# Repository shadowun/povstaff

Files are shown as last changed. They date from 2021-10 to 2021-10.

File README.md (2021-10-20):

# POV staff
This repository contains all files related to Persistence of Vision (POV) staff
project. A detailed write-up of this project is available on  Instructables at
[https://www.instructables.com/Persistence-of-Vision-LED-Staff/](https://www.instructables.com/Persistence-of-Vision-LED-Staff/);
you can also find there photos  of the staff in action.

A guide for using the assembled staff and uploading images to it is available
in directory `docs`; see file USER_GUIDE.md and USER_GUIDE.pdf for PDF version.

## Structure of this repository  
This repository is organized as follows:

* `binaries`: pre-complied binaries
* `docs`: documentation
* `hardware`:  design files for the custom PCBs used in
  the project, as well as STEP files for the 3d printed components.
* `images`: sample image(s) and  `imagelist.txt` file

## Authors and license
This project was created by Alexander Kirillov <shurik179@gmail.com>; it is
based on [earlier work](https://learn.adafruit.com/pov-dotstar-double-staff) of
Phillip Burgess and Erin St Blaine from Adafruit. The project is available under
MIT license; see LICENSE file for details.

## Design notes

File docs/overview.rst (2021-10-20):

*********************
Overview
*********************

It is well known that even after a light has been turned off, human eye keeps
"seeing" it for a fraction of second. This is known as Persistence of Vision, or
POV, and it allows one to "paint" pictures by quickly moving a strip of LEDs,
drawing one line of an image at a time in quick succession. If you search online
(e.g. on Etsy), you can find quite a few toys based on this idea: pois, staffs,
and more.

However, these are expensive: typical prices for a POV staff of decent
resolution start at $500, and they use proprietary software, so there is no easy
way to modify their behavior or add extra functionality. Thus, when looking for
a birthday gift for a friend who enjoys painting with light, I decided to create
my own open source version using readily available components.

My project builds upon the outstanding `work of Phillip Burgess and Erin St
Blaine <https://learn.adafruit.com/pov-dotstar-double-staff>`__ from Adafruit;
however, I made a few changes, upgrading the electronics.
Below are key features of this project:

* It is a two-sided staff, of total length 141 cm (55in); it is not collapsible.
  Each side of the staff has two 50cm/72 pixels LED strips, for the total of 288
  LEDs. Thus, you can use it to show images with 72-px resolution.

* Staff is powered by two 18650 Li-Ion batteries, which should be enough for at
  least 1 hr show, possibly as much as 2 hours, depending on intensity of your
  images. The batteries can be recharged via micro-USB connector; full charge
  time is about 5 hrs.

* Images (in bitmap format) can be easily uploaded to the
  staff by connecting the staff to a computer, where it appears as a USB
  storage device. It has enough memory for about 50 images. The order in which
  images are shown is described in a separate plain text file, where you can
  put a list of images and durations. An image can be listed there several
  times, or none at all.

* The staff contains an Inertial Motion Unit (IMU) which can be used to
  detect when the staff is in motion. The software uses it to adjust update
  frequency for images, so the images will not appear stretched or compressed
  regardless of how fast you are rotating it. You can also use it for
  controlling your show: e.g. stopping the staff horizontally is used as a
  signal to move to the next image in the slideshow. The software is based on
  Arduino IDE. It is available under an open source license and is easy to
  modify to suit your needs.

This project is open source; all code and schematics are available in my github
repository under MIT license.

For those who want to create your own staff, you can buy a kit of parts, which
includes most of the parts needed (except for LED strips and tube), from my
`Tindie store <https://www.tindie.com/stores/irobotics/>`__. Of course, you
can also build your own by sourcing all components independently -- see
building instructions for details.

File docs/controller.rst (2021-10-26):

=====================
Soldering
=======================
Solder the male headers to the ItsyBitsy; for ItsyBitsy M4, only solder the
headers along the two long sides of the board. Now solder the POV shield board
to these headers underneath the Itsy Bitsy, forming a "sandwich" of two boards
as shown in the photos above. Note: all components of the POV shield should be
on the outside, not inside the sandwich!

After you are done soldering, use diagonal cutters to trim the long pins of the
headers so they are not in the way.

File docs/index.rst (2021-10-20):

===========================
Persistence of Vision Staff
===========================
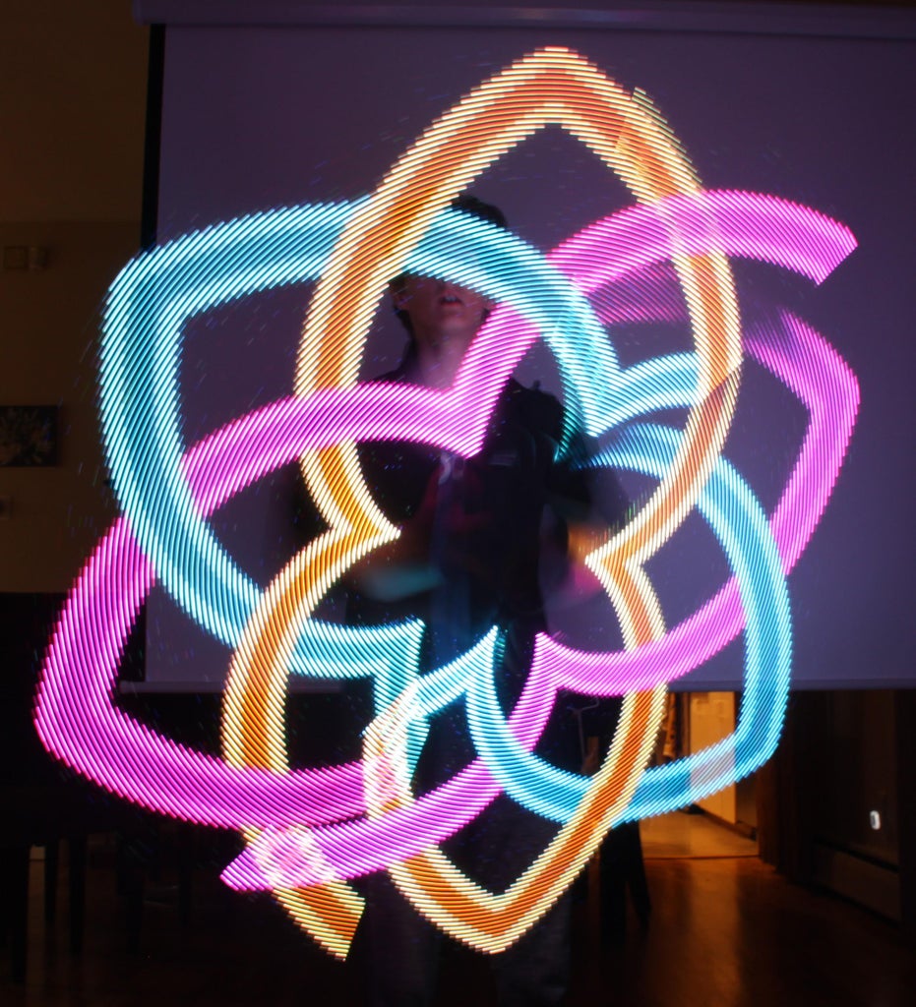
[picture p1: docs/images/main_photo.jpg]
Staff in action


This is documentation for Persistence of Vision (POV) staff, created  by Alexander
Kirillov (based on earlier work of ). An earlier version of this project has
been published on `Instructables <https://www.instructables.com/Persistence-of-Vision-LED-Staff/>`__.
This document describes a new and improved Version 2, created in 2021.

All design files and code are opne source.

.. toctree::
    :caption: Table of Contents
    :maxdepth: 2

    overview
    build
    usage

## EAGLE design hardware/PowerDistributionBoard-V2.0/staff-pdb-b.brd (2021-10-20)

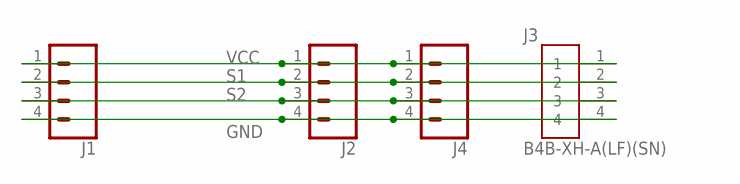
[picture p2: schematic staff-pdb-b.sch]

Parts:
J1, J2, J4: CONN_04; 1X04
J3: B4B-XH-A(LF)(SN); JST_B4B-XH-A(LF)(SN)

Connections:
GND: J1.4, J2.4, J3.4, J4.4
S1: J1.2, J2.2, J3.2, J4.2
S2: J1.3, J2.3, J3.3, J4.3
VCC: J1.1, J2.1, J3.1, J4.1

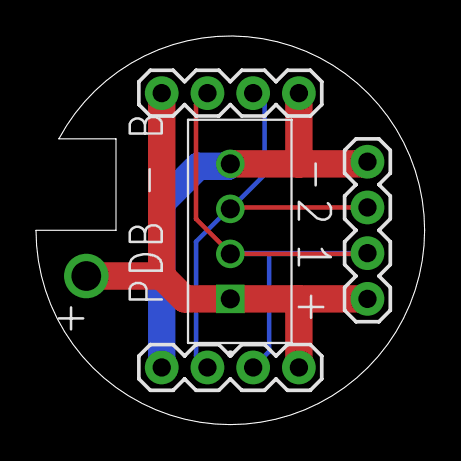
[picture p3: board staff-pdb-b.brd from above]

Board: 2 copper layers, 21.6 x 21.6 mm, 4 parts (0 on the bottom side), 4 nets.

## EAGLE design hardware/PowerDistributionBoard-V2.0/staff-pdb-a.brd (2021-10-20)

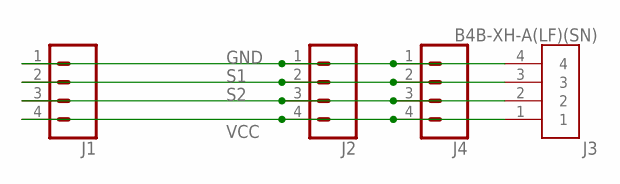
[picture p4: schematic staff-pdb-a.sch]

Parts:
J1, J2, J4: CONN_04; 1X04
J3: B4B-XH-A(LF)(SN); JST_B4B-XH-A(LF)(SN)

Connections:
GND: J1.1, J2.1, J3.4, J4.1
S1: J1.2, J2.2, J3.3, J4.2
S2: J1.3, J2.3, J3.2, J4.3
VCC: J1.4, J2.4, J3.1, J4.4

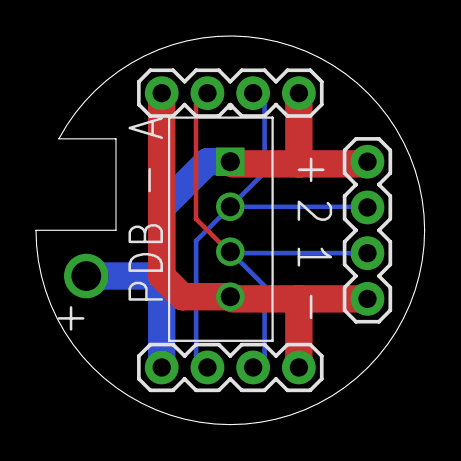
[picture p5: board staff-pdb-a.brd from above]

Board: 2 copper layers, 21.6 x 21.6 mm, 4 parts (0 on the bottom side), 4 nets.

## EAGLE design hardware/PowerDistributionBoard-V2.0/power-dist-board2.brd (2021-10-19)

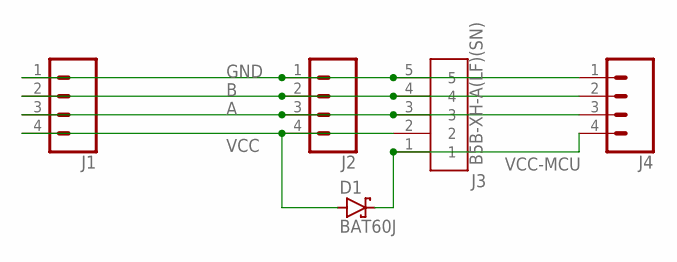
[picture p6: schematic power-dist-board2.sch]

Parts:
D1: BAT60J; SOD323_ST
J1, J2, J4: CONN_04; 1X04
J3: B5B-XH-A(LF)(SN); JST_B5B-XH-A(LF)(SN)

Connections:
A: J1.3, J2.3, J3.3, J4.3
B: J1.2, J2.2, J3.4, J4.2
GND: J1.1, J2.1, J3.5, J4.1
VCC: D1.A, J1.4, J2.4, J3.2
VCC-MCU: D1.C, J3.1, J4.4

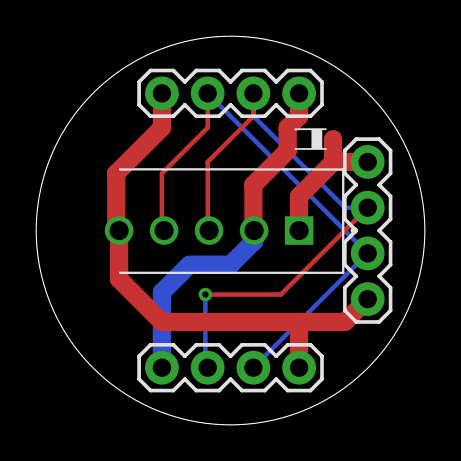
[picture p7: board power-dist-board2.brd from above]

Board: 2 copper layers, 21.6 x 21.6 mm, 5 parts (0 on the bottom side), 5 nets.

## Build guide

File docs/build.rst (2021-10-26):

*********************
Building instructions
*********************
Below you can find the instructions for building your own POV staff. These
instructions assume that you are using a kit of parts bought from my
`Tindie store <https://www.tindie.com/stores/irobotics/>`__. Some information
on modifying these instructions if you want to source your components independently
is given in section FIXME.

You will need the following materials:

* Kit of parts from https://www.tindie.com/stores/irobotics/

* APA102 (DotStar) LED strip, 144 LED/meter, black PCB. They are  found from
  many vendors, including  `Adafruit <https://www.adafruit.com/product/2241>`__
  and a number of vendors on Amazon and Aliexpress, such as `<https://www.aliexpress.com/item/32322326979.html>`__.
  You need 4 strips of 50cm (72 LEDs) each; you can also buy longer strips
  and cut them into 50cm pieces. The strips should **not** be waterproofed
  (sometimes this is listed as IP30). Adafruit strips come with waterproof
  silicone sheathing which you can just remove and discard.

* Two 18650 Li-Ion batteries. Look for high-capacity (at least 3000mAh),
  **protected batteries** from a reputable manufacturer such as Panasonic, Samsung,
  or Sanyo; I recommend `these batteries
  <https://www.18650batterystore.com/collections/button-top-18650-batteries/products/panasonic-18650-protected>`__
  by Panasonic. Do not try to  save money by buying a no-name battery on eBay or Amazon.

* Polycarbonate tube, `11F(55in/141cm) <https://flowtoys.com/long-tubes-5f-to-13f>`__,
  1 inch outer diameter, from flowtoys.com

* 1/2 inch square wood dowel, from HomeDepot or any other hardware store.
  You need 4 ft (or two 2ft pieces)

In addition, you will need some spray black paint, a soldering iron, and some
common tools: sharp knife, saw (for cutting wood dowel), diagonal cutters for
trimming header pins, scissors. Needless to say, you will also need a computer
to program the microcontroller and a USB charger to charge the batteries.

.. toctree::
    :caption: Steps
    :maxdepth: 2

    build_overview
    led_assemblies
    controller

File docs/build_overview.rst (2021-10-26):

========================
Overview of build steps
========================

The assembled staff will consist of the following subassemblies:

* Two 18650 batteries and wiring in the middle of the staff. The batteries are
  separated from each other and from LED assemblies by 3d printed spacers; total
  length of the batteries+spacers is about 25 cm.

* Two LED assemblies, one on each side of the staff. Each assembly consists of
  two 50 cm LED strips attached to a wood dowel. The LED strips will be soldered
  to a round power distribution board at the interior end of the dowel. The LED
  assembly are connected to each other and battery by JST XH connectors,
  plugging into the headers on power distribution boards.

* At one end of the staff, there is a switch, with two wires leading from it to
  the batteries in the middle and protected by a PVC endcap with an opening for the
  switch

* At the opposite end of the staff, the controller, consisting of the ItsyBitsy
  microcontroller attached to the custom POV shield board, protected by PVC endcap.
  A 4-wire cable is plugged into the JST XH header on the POV shield; the wires
  run the length of LED assembly to the center

* Tennis racket grip tape covering the battery assembly in the middle of the
  staff, for better grip.

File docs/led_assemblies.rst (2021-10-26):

============================
Making the LED assemblies
============================

1. Take the 1/2 inch wood dowels and cut them using hacksaw to produce two
   pieces of 52cm each. Try to keep your cuts square.

2. Spray-paint the pieces black and leave to dry. This will give the staff a
   much more polished look (while it is off; once it is on, no one will notice
   what color the dowels are).

3. Get the LED strip(s). If they are inside waterproof sheaving, remove and
   discard the sheaving. If they have any wires soldered, de-solder them;
   remove excess solder using a braid wick. If you ordered 1m or 2m strips, cut
   them into 50 cm pieces, making sure to leave as large as possible soldering
   pads in the beginning of each strip (this should be easy, as usually longer
   strips are created by soldering together 50cm ones, so you will be just
   undoing someone else's work).

4. Using your soldering iron, tin the pads in the beginning of each LED strip.
   Take the solid core wire included in the kit of parts; strip insulation from
   about 2cm  long piece but do not cut it. Using the insulated part to hold the
   wire, solder it to the top pad on the strip. You will be soldering very
   close to the first LED, so please watch your iron carefully - do not touch the LED!
   After soldering, cut the soldered piece and repeat the process with all
   other pads. The end result should look similar to the one shown below:

5. Now    
All APA102 strips have 4 signal lines: Ground (GND, commonly abbreviated G), Clock (CLK, or CI for Clock In), Data (DAT, or DI), and VCC, or 5V. However, the order of these signal lines on the strips is varies between manufacturers. Thus, now is a good time to write it down for future use. Put the strip on the desk with the beginning of the strip to the left, and write down the signals, going from top to bottom and labeling them A... D. For example, for the strip in the photos above you would get the following list:
A=GND
B=CLK
C=DAT
D=VCC
Keep this list readily available through the rest of assembly - you will refer to it more than once.

Remove the backing paper from the adhesive strip on the back of the LED and attach the strip to the wood dowel so that the plastic spacers on the soldered headers are flush with the end of the dowel. Attach the other strip to the opposite side of the dowel. Repeat with the other dowel.
Take the power distribution boards and solder them to the headers as shown in the photos. The boards should be flush with the end of the wood dowel. Use diagonal cutters to cut off extra length of header pins.
You should now have two completed LED assemblies.
Note: the adhesive on LED strips is not very strong, so your strips might start peeling off. It is OK; we will make a more permanent attachment later.

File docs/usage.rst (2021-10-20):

*********************
User guide
*********************


This document describes the use of the POV staff. It assumes you have already
fully assembled it and uploaded the software. For more information, please
check the description of the project on instructables.com:
https://www.instructables.com/Persistence-of-Vision-LED-Staff/

The latest version of this document can always be found on the project github page:
https://github.com/shurik179/povstaff

## Turning on/off
To turn the staff on and off, use the switch at one end of the staff. As soon
as you have turned it on, it will show the battery voltage, by lighting part
of the LED strips. The longer the strip, the higher the battery charge.

If you only see one or two LEDs light up, the battery charge is too low for
use. You need to recharge the batteries as described below.

After using the staff, **make sure to turn it off**! If left on, LEDs will
drain the battery rather fast - even if you are not using the staff. To remind
you to turn it off, the staff will be blinking  red LEDs once every 30 seconds
while it is on and not being used.

## Charging/recharging
To charge the staff, remove the endcap from the end opposite to the switch.
Inside you will see a microcontroller with a micro-USB connector. Plug in a
USB charger; for best results, use a charger that can provide at least 1A
charging current.

For charging, the switch must be in ON position. Once you completed charging,
remember to switch the staff off.

Full charge should take about 5 hrs.

## Uploading images and creating image list
To upload images, make sure the switch is OFF and connect the staff to a
computer. It should appear as an external USB drive - as if you had plugged
in a USB flash drive. Just drag the images to the staff to upload. All images
must be saved to the root directory of the staff drive - please do not create
subdirectories.

Technical requirements for images:

* Images must be in bitmap (BMP) format, with 24 bit color depth. Use any
  software you like to convert images in other formats to bmp - e.g. you can use
  Microsoft Paint 3D.

* Maximal image size is 72x288 pixels. It is recommended to use images with
  width of 72 pixels - to match the number of LEDs on the staff

* Image filenames must be at most 30 symbols long and can only contain letters,
  numbers, dashes and underscores. No spaces or special symbols!

You can create your own images or search for existing ones.  A good source for
POV image patterns is [Visual  POI Zone](https://visualpoi.zone/patterns/).
When downloading images from there, make sure to choose *Visual poi V4 mini (72px)*
option. You will also need to rotate images 90 degrees.

Please note that the same color (i.e. the same RGB values) can look quite
different on the screen of your computer and on LED strip. Experiment with
colors to get some feel for it.

Once you have uploaded the images, you need to create a list showing in which
order these images should be played during the show. Create the file
`imagelist.txt` in the root directory of the POV staff (or open the file if
it already exists) and put there the list of image files in the order you want
to use them in your show, one filename per line, including `.bmp` extension.
Optionally, you can also add how long the image should be shown, in seconds
(whole numbers only!), separated from  filename by one or more spaces
```
image1.bmp 20
image2.bmp 41
image5.bmp 10
image1.bmp
```
You can include some image file more than once, or not at all - it is your
choice. The name of your image list must be `imagelist.txt`, all lower case.

Once you have saved the image list,  eject the POV staff as you would normally
do a USB flash drive, and unplug the cable.

To help you figure out correct rotation and orientation of images, the pictures
below show the same image in BMP file and how it will look when using the POV staff.

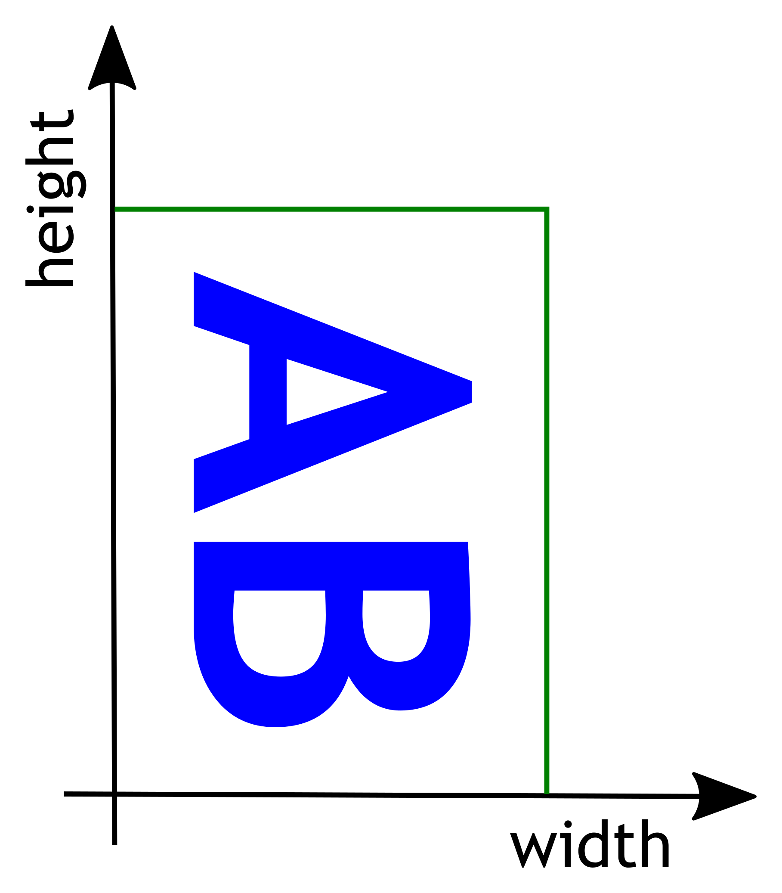
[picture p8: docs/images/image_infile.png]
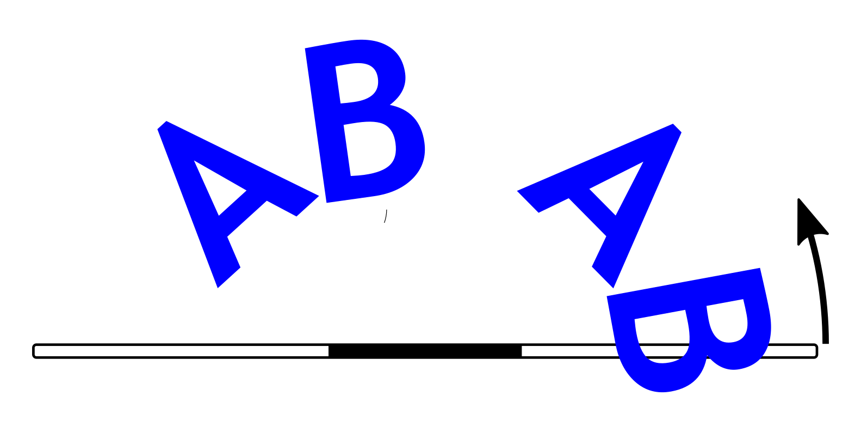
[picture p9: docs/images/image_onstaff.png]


Directory `images` in the (github repository)[https://github.com/shurik179/povstaff]
contains some sample images and `imagelist.txt` file; to get started, you can
just copy the contents  of that directory to root directory of your staff.

## Using the staff
Now we are finally ready to use the staff. Turn the switch  ON; keep the
staff (more or less) stationary and  wait until it shows the voltage indicator.
After that the staff will go blank  waiting for you to start the show.

To start the show, just start rotating the staff. As soon as rotation speed is
high enough, the staff will begin showing your first image, one line at a time,
and will continue doing that as long as you are twirling the staff. It will
adjust the interval between successive lines depending on the rotation speed,
to keep the image ratio close to original regardless of how fast you are
rotating the staff.

The staff will continue showing the image for the duration given in
`imagelist.txt` file or until you pause the staff as described below, whatever
comes first. If duration for a given image was not provided, the staff will
continue showing this image until you pause.

To pause the show or move to the next image in the list, stop the staff
**in horizontal position**. It will go blank; as soon as you start twirling it
again, it will resume the show, moving to the next image. After reaching the
last image in the list, it will loop over, starting again with the first image.

After you are done, do not forget to **turn the staff OFF**, to avoid draining
the batteries.

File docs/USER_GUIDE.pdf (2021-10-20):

# POV Staff User Guide

## by Alexander Kirillov

This document describes the use of the POV staff. It assumes you have already fully assembled it and uploaded the software. For more information, please check the description of the project on instructables.com: https://www.instructables.com/Persistence-of-Vision-LED-Staff/ (https://www.instructables.com/Persistence-of-Vision-LED-Staff/)

The latest version of this document can always be found on the project github page: https://github.com/shurik179/povstaff

## Turning on/off

To turn the staff on and off, use the switch at one end of the staff.
As soon as you have turned it on, it will show the battery voltage,

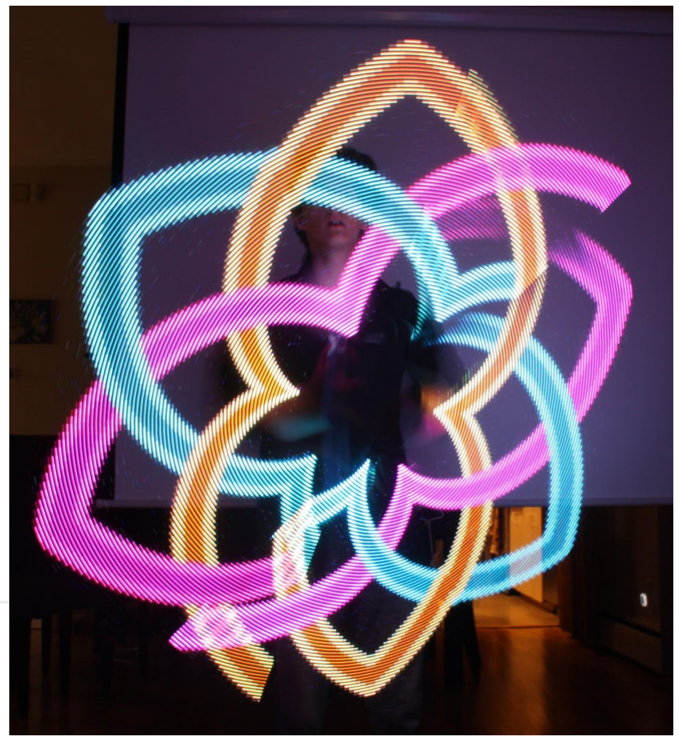
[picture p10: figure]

by lighting part of the LED strips. The longer the strip, the higher the battery charge.

If you only see one or two LEDs light up, the battery charge is too low for use. You need to recharge the batteries as described below.

After using the staff, make sure to turn it off! If left on, LEDs will drain the battery rather fast - even if you are not using the staff. To remind you to turn it off, the staff will be blinking red LEDs once every 30 seconds while it is on and not being used.

## Charging/recharging

To charge the staff, remove the endcap from the end opposite to the switch. Inside you will see a microcontroller with a micro-USB connector. Plug in a USB charger; for best results, use a charger that can provide at least 1A charging current.

For charging, the switch must be in ON position. Once you completed charging, remember to switch the staff off.

Full charge should take about 5 hrs.

## Uploading images and creating image list

To upload images, make sure the switch is OFF and connect the staff to a computer. It should appear as an external USB drive - as if you had plugged in a USB flash drive. Just drag the images to the staff to upload. All images must be saved to the root directory of the staff drive - please do not create subdirectories.

Technical requirements for images:

Images must be in bitmap (BMP) format, with 24 bit color depth. Use any software you like to convert images in other formats to bmp - e.g. you can use Microsoft Paint 3D.

Maximal image size is 72x288 pixels. It is recommended to use images with width of 72 pixels - to match the number of LEDs on the staff

Image filenames must be at most 30 symbols long and can only contain letters, numbers, dashes and underscores. No spaces or special symbols!

You can create your own images or search for existing ones. A good source for POV image patterns is Visual POI Zone. (https://visualpoi.zone/patterns/) When downloading images from there, make sure to choose Visual poi V4 mini (72px) option. You will also need to rotate images 90 degrees.

Please note that the same color (i.e. the same RGB values) can look quite different on the screen of your computer and on LED strip. Experiment with colors to get some feel for it.

Once you have uploaded the images, you need to create a list showing in which order these images should be played during the show. Create the file imagelist.txt in the root directory of the POV staff (or open the file if it already exists) and put there the list of image files in the order you want to use them in your show, one filename per line, including .bmp extension. Optionally, you can also add how long the image should be shown, in seconds (whole numbers only!), separated from filename by one or more

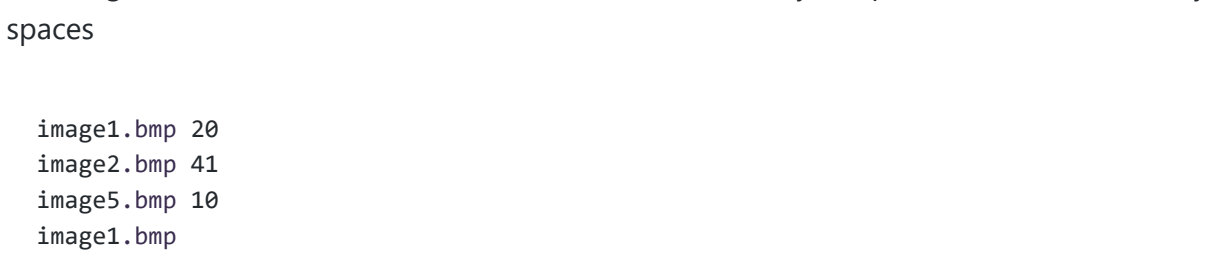
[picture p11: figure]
spaces; image1.bmp 20 image2.bmp 41 image5.bmp 10 image1.bmp

You can include some image file more than once, or not at all - it is your choice. The name of your image list must be imagelist.txt , all lower case.

Once you have saved the image list, eject the POV staff as you would normally do a USB flash drive, and unplug the cable.

To help you figure out correct rotation and orientation of images, the pictures below show the same image in BMP file and how it will look when using the POV staff.

Directory images in the (github repository)[https://github.com/shurik179/povstaff] contains some sample images and imagelist.txt file; to get started, you can just copy the contents of that directory to root directory of your staff.

## Using the staff

Now we are finally ready to use the staff. Turn the switch ON; keep the staff (more or less) stationary and wait until it shows the voltage indicator. After that the staff will go blank waiting for you to start the show.

To start the show, just start rotating the staff. As soon as rotation speed is high enough, the staff will begin showing your first image, one line at a time, and will continue doing that as long as you are twirling the staff. It will adjust the interval between successive lines depending on the rotation speed, to keep the image ratio close to original regardless of how fast you are rotating the staff.

The staff will continue showing the image for the duration given in imagelist.txt file or until you pause the staff as described below, whatever comes first. If duration for a given image was not provided, the staff will continue showing this image until you pause.

To pause the show or move to the next image in the list, stop the staff in horizontal position. It will go blank; as soon as you start twirling it again, it will resume the show, moving to the next image. After reaching the last image in the list, it will loop over, starting again with the first image.

After you are done, do not forget to turn the staff OFF, to avoid draining the batteries.

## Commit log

2021-10-19 updating boards
    [power-dist-board2.brd, power-dist-board2.sch]
2021-10-20 rearranging files
    [staff-pdb-a.brd, staff-pdb-a.sch, staff-pdb-b.brd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]
